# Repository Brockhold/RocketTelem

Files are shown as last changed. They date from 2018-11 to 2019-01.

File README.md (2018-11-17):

# CSS427-Project
# Team Rocket

### Members
**Robert Bachta**
**Ben Rockhold**

### Hardware / Sensors
- Adafruit Feather M0 Bluefruit
- Adafruit Feather M0 Adalogger
- (2) Sparkfun RFM69HCW 915MHz Wireless Transceiver
- Ultimate GPS Breakout v3
- Adafruit 10 DOF (LSM303DLHC Accel/Mag, L3GD20H Gyroscope, BMP180 Temp/Baro)

### Software
- Adafruit_GPS.h
- Adafruit_Sensor.h
- Adafruit_LSM303_U.h
- Adafruit_BMP085_U.h
- Adafruit_L3GD20_U.h
- Adafruit_10DOF.h
- RH_RF69.h

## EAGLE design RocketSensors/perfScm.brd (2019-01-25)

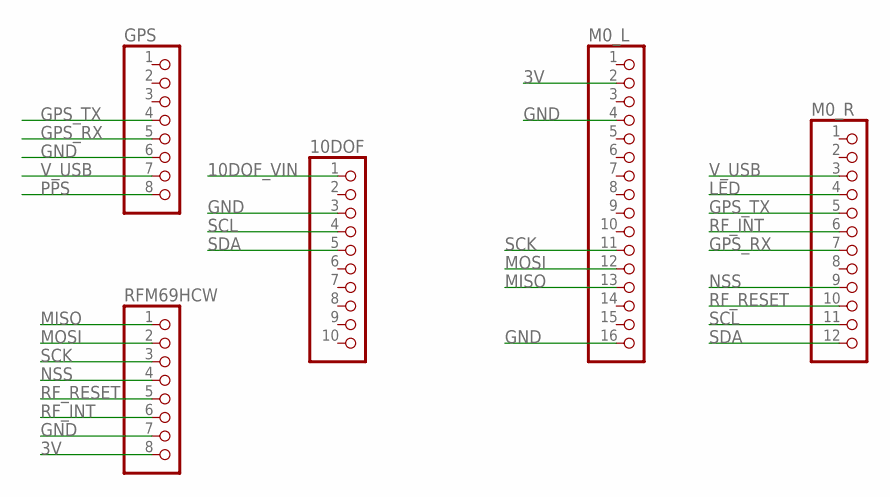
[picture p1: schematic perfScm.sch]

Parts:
10DOF: PINHD-1X10; 1X10
GPS: PINHD-1X8; 1X08
M0_L: PINHD-1X16; 1X16
M0_R: PINHD-1X12; 1X12
RFM69HCW: PINHD-1X8; 1X08

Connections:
3V: M0_L.2, RFM69HCW.8
10DOF_VIN: 10DOF.1
GND: 10DOF.3, GPS.6, M0_L.4, M0_L.16, RFM69HCW.7
GPS_RX: GPS.5, M0_R.7
GPS_TX: GPS.4, M0_R.5
LED: M0_R.4
MISO: M0_L.13, RFM69HCW.1
MOSI: M0_L.12, RFM69HCW.2
NSS: M0_R.9, RFM69HCW.4
PPS: GPS.8
RF_INT: M0_R.6, RFM69HCW.6
RF_RESET: M0_R.10, RFM69HCW.5
SCK: M0_L.11, RFM69HCW.3
SCL: 10DOF.4, M0_R.11
SDA: 10DOF.5, M0_R.12
V_USB: GPS.7, M0_R.3

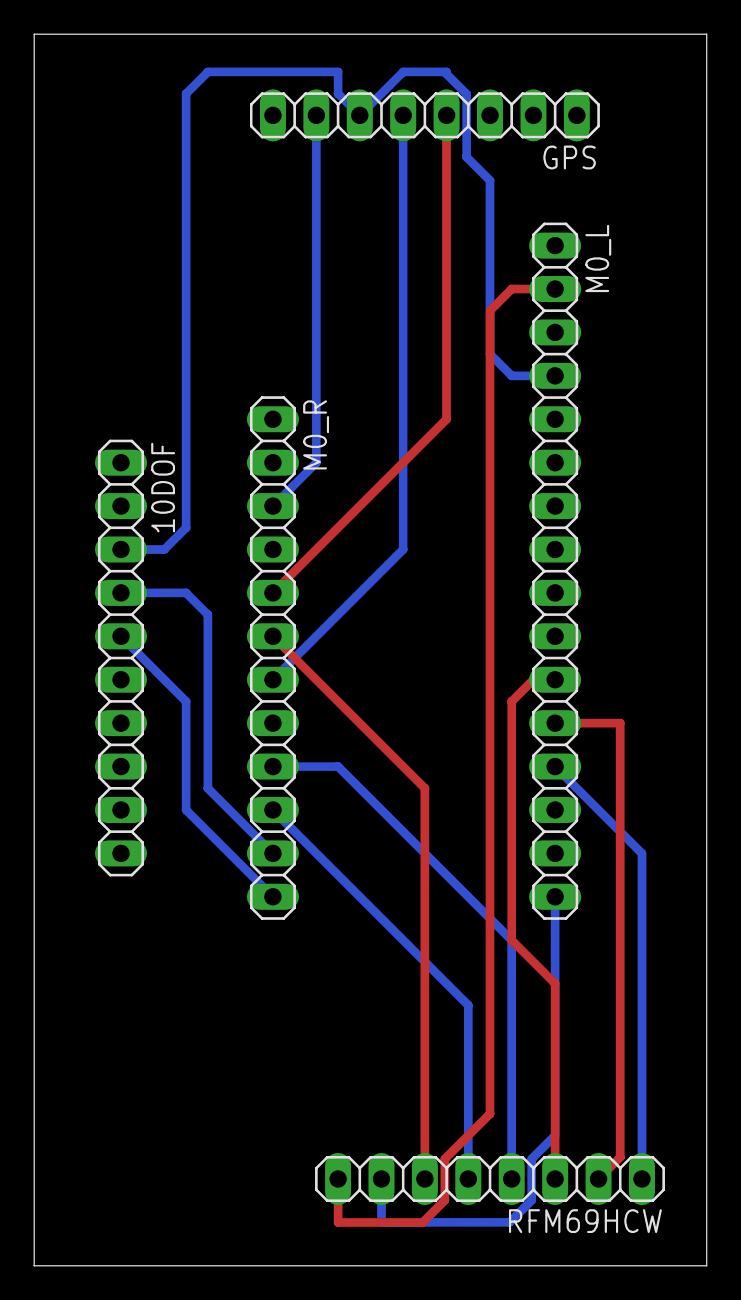
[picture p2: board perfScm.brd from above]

Board: 2 copper layers, 39.4 x 72.1 mm, 5 parts (0 on the bottom side), 13 nets.

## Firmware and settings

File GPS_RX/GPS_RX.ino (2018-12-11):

/*
 * Sketch for receiving sensor data from remote device..
 * 
 * Hardware: 
 *  Adafruit M0 (currently using BTLE Bluefruit, but not using the BT module)
 *  RF69HCW radio tranceiver connected to SPI (see config.h for pin details)
 */

#include "config.h"
#include "radioDecode.h"

RH_RF69 rf69(RFM69_CS, RFM69_INT); // radio driver instance
Adafruit_BluefruitLE_SPI ble(BLUEFRUIT_SPI_CS, BLUEFRUIT_SPI_IRQ, BLUEFRUIT_SPI_RST);

void usageMessage() {
  Serial.print(" | To set a polling rate enter a value between "); Serial.print(MINPERIOD);
  Serial.println("ms and 10000ms into the Serial input.");
  Serial.println(" |     Entering '0' or <emptystring> returns the current status and enters on-demand mode.");
  Serial.println(" |     Sending 's 0' and 's 1' enables or disables sd logging respectively.");
  Serial.println(" |     Sending 's 2' creates a new log file. Sending 's 9' erases the current log.");
}

// RF Initialize Method
void rfInitialize(){
  // manual reset
  digitalWrite(RFM69_RST, HIGH);
  delay(10);
  digitalWrite(RFM69_RST, LOW);
  delay(10);
  
  if (!rf69.init()) {
    Serial.println("[!] RFM69 radio init failed");
    while (1);
  }
  Serial.println("[!] RFM69 radio init OK!");
  
  // Defaults after init are 434.0MHz, modulation GFSK_Rb250Fd250, +13dbM (for low power module)
  // No encryption
  if (!rf69.setFrequency(RF69_FREQ)) {
    Serial.println("setFrequency failed");
  }

  // If you are using a high power RF69 eg RFM69HW, you *must* set a Tx power with the
  // ishighpowermodule flag set like this:
  rf69.setTxPower(20, true);  // range from 14-20 for power, 2nd arg must be true for 69HCW

  // The encryption key has to be the same as the one in the server
  uint8_t key[] = { 0x01, 0x02, 0x03, 0x04, 0x05, 0x06, 0x07, 0x08,
                    0x01, 0x02, 0x03, 0x04, 0x05, 0x06, 0x07, 0x08};
  rf69.setEncryptionKey(key);

  Serial.print("[!] RFM69 radio @");  Serial.print((int)RF69_FREQ);  Serial.println(" MHz");
}

bool btInit() {
  ble.begin(VERBOSE_MODE);
  ble.factoryReset();
  ble.echo(false);
  ble.verbose(false);
  
  ble.setMode(BLUEFRUIT_MODE_DATA);
}

// toggle the given pin by some count # of times for a duration of 'wait'
void blink(int pin, int count, int wait) {
  bool state = false;
  for (int i = 0; i < count * 2; i++) {
    digitalWrite(pin, state?HIGH:LOW);
    state = !state;
    delay(wait);
  }
}

/**
 * Reads integer from Serial to set polling rate on TX
 */
void readInput(){
  //send 0 or <emptystring> for on-demand mode. press enter to receive data.
  if(Serial.available()){

    //count of commands received
    ++terminalCounter;
    Serial.print("[!] Terminal command received. Current Count: ");
    Serial.println(terminalCounter);

    if(Serial.peek() == 's'){
      polling s;
      char sdCard = Serial.read(); //remove the s
      uint8_t sdCommand = Serial.parseInt(); //parse the number
      Serial.print("Sending SD Card update: "); Serial.print(sdCard); Serial.print(" "); Serial.println(sdCommand);
      s.sdCommand = sdCommand;
      s.message_id = counter;
      s.sdCard = sdCard;
      
      ++counter;
      rf69.send((uint8_t *)&s, sizeof(s));
      rf69.waitPacketSent();
      
      clearBuffer();
      usageMessage();
      return;
    }
    
    polling p;
    p.polling_rate = Serial.parseInt();
    p.message_id = counter;
    
    // clears out buffer for next read
    clearBuffer();

    // check validity of polling rate
    if ((p.polling_rate == 0) || (p.polling_rate >= MINPERIOD)) {
      // Send polling rate to TX
      ++counter;
      rf69.send((uint8_t *)&p, sizeof(p));
      rf69.waitPacketSent();
      
      // tell the user about the new polling rate, and optionally the usage
      if(p.polling_rate == 0){
        Serial.println("[!] Requested On-Demand update(s)");
        usageMessage();
      } else {
        Serial.print("[!] Polling rate has been updated to: ");
        Serial.print(p.polling_rate); Serial.println("ms");
      }
    } else {
      Serial.print(p.polling_rate); Serial.println("ms is too fast, please enter another value.");
      delay(2000);
    }
  }
}

void readBTInput() {
  //send 0 or <emptystring> for on-demand mode. press enter to receive data.
  if(ble.available()){

    //count of commands received
    ++terminalCounter;
    ble.print("[!] BT command received. Current Count: ");
    ble.println(terminalCounter);

    if(ble.peek() == 's'){
      polling s;
      char sdCard = ble.read(); //remove the s
      uint8_t sdCommand = ble.parseInt(); //parse the number
      ble.print("Sending SD Card update: "); ble.print(sdCard); ble.print(" "); ble.println(sdCommand);
      s.sdCommand = sdCommand;
      s.message_id = counter;
      s.sdCard = sdCard;
      
      ++counter;
      rf69.send((uint8_t *)&s, sizeof(s));
      rf69.waitPacketSent();
      
      clearBuffer();
      usageMessage();
      return;
    }
    
    polling p;
    p.polling_rate = ble.parseInt();
    p.message_id = counter;
    
    // clears out buffer for next read
    clearBuffer();

    // check validity of polling rate
    if ((p.polling_rate == 0) || (p.polling_rate >= MINPERIOD)) {
      // Send polling rate to TX
      ++counter;
      rf69.send((uint8_t *)&p, sizeof(p));
      rf69.waitPacketSent();
      
      // tell the user about the new polling rate, and optionally the usage
      if(p.polling_rate == 0){
        ble.println("[!] Requested On-Demand update(s)");
        usageMessage();
      } else {
        ble.print("[!] Polling rate has been updated to: ");
        ble.print(p.polling_rate); ble.println("ms");
      }
    } else {
      ble.print(p.polling_rate); ble.println("ms is too fast, please enter another value.");
      delay(2000);
    }
  }
}

/**
 * Sends received packet data to Serial
 */
void displayPacketData(statusStruct &packet){
  Serial.println("<packet>");
  Serial.println("  Metadata:");

  #if DEBUG
    Serial.print("    Raw = {"); 
    for (int i = 0; i < sizeof(packet); i++) {
      Serial.print(' '); Serial.print(((uint8_t *)&packet)[i]); 
    }
    Serial.println("}");
  #endif

  Serial.print("    Message ID: "); Serial.println(packet.message_id);
  Serial.print("    Current Polling Rate: ");
  if(packet.polling_rate < 2){
   Serial.println("On-Demand");
  }else{
   Serial.print(packet.polling_rate); Serial.println("ms");
  }
  Serial.print("    Logging Status: "); Serial.println(packet.sdStatus ? "Enabled" : "Disabled");
  
  Serial.print("  Date & Time:    "); 
  // Year/Month/Day
  Serial.print(packet.year); Serial.print("/");
  Serial.print(packet.month); Serial.print("/");
  Serial.print(packet.day);
  Serial.print("    ");
  // Hour:Minute:Second
  Serial.print(packet.hour); Serial.print(":");
  Serial.print(packet.minute); Serial.print(":");
  Serial.println(packet.seconds);

  Serial.println("  Transmitter Status:");
  
  // Transmitter battery level
  Serial.print("    Battery voltage: "); Serial.print((float)packet.batt_level / 1024); Serial.println("v");
  Serial.print("    Temperature (C): "); Serial.println(packet.temperature);

  Serial.println("  Physical Status:");
  
  // GPS reception status
  Serial.print("    GPS fix: "); Serial.print(packet.fix?"Yes":"No");
  Serial.print(", Quality: "); Serial.print(packet.fixquality);
  Serial.print(", Satellites: "); Serial.println(packet.satellites);

    // If there is a GPS fix, print the reported Lat & Ln
    if (packet.fix) {
      Serial.print("    Location: ");
      if ((char) packet.lat == 'S') Serial.print("-");
      Serial.print(packet.latitude_fixed/10000000); Serial.print("."); Serial.print(packet.latitude_fixed % 10000000);
      Serial.print(", ");
      if ((char) packet.lon == 'W') Serial.print("-");
      Serial.print(packet.longitude_fixed/10000000); Serial.print("."); Serial.println(packet.longitude_fixed % 10000000);
    } else {
      Serial.println("    Location: +000.000000, +000.000000");
    }
    // Barometric altimeter status
    Serial.print("    Altitude: "); Serial.println(abs(packet.bar_alt));
    // Accelerometer status
    Serial.print("    Accelerometer {"); 
    Serial.print(" Pitch: "); Serial.print((float)(packet.pitch) / 700); 
    Serial.print(" Roll: "); Serial.print((float)(packet.roll) / 300);
    Serial.print(" Heading: "); Serial.print((float)(packet.heading) / 180);
    Serial.println(" }");
    //Serial.print("Compass Heading: "); Serial.println(packet.mag_heading);
    
    Serial.println("</packet>"); Serial.println();
 }

void btPrint(statusStruct &packet) {
  ble.print("Packet ID: "); ble.print(packet.message_id);
  ble.print(" rate: ");
  if(packet.polling_rate < 2){
   ble.println("On-Demand");
  }else{
   ble.print(packet.polling_rate); ble.println("ms");
  }
  ble.print("Log: "); ble.println(packet.sdStatus ? "Yes" : "No");
  
  // Year/Month/Day
  ble.print(packet.year); ble.print("/");
  ble.print(packet.month); ble.print("/");
  ble.print(packet.day);
  ble.print("    ");
  // Hour:Minute:Second
  ble.print(packet.hour); ble.print(":");
  ble.print(packet.minute); ble.print(":");
  ble.println(packet.seconds);

  // Transmitter battery level
  ble.print((float)packet.batt_level / 1024); ble.println("v");
  ble.print(packet.temperature); ble.println("c"); 

  // GPS reception status
  ble.print("Fix: "); ble.print(packet.fix?"Yes":"No");
  ble.print(", Q: "); ble.print(packet.fixquality);
  ble.print(", Sats: "); ble.println(packet.satellites);

    // If there is a GPS fix, print the reported Lat & Ln
    if (packet.fix) {
      ble.print("Loc: ");
      if ((char) packet.lat == 'S') ble.print("-");
      ble.print(packet.latitude_fixed/10000000); ble.print("."); ble.print(packet.latitude_fixed % 10000000);
      ble.print(", ");
      if ((char) packet.lon == 'W') ble.print("-");
      ble.print(packet.longitude_fixed/10000000); ble.print("."); ble.println(packet.longitude_fixed % 10000000);
    }
    // Barometric altimeter status
    ble.print("Alt: "); Serial.println(packet.bar_alt);
    // Accelerometer status
    ble.print("Accel{"); 
    ble.print(" P: "); ble.print((float)(packet.pitch) / 700); 
    ble.print(" R: "); ble.print((float)(packet.roll) / 300);
    ble.print(" H: "); ble.print((float)(packet.heading) / 180);
    ble.println(" }\n");
}

 /*
 * SETUP
 */
void setup() {
  Serial.begin(115200);
  while (!Serial) { delay(1); } // wait until serial console is open, remove if not tethered to computer

  pinMode(LED_BUILTIN, OUTPUT); digitalWrite(LED_BUILTIN, LOW);
  pinMode(RFM69_RST, OUTPUT);
  digitalWrite(RFM69_RST, LOW);

  rfInitialize();
  btInit();
  usageMessage();
}

/*
 * Program Loop
 */

void loop() {
  
  readInput(); // check for new polling rate directive from user
  //readBTInput();
  struct statusStruct radioPacket;
  uint8_t len = sizeof(radioPacket);
  if (rf69.available() && rf69.recv((uint8_t *)&radioPacket, &len)) {
    if (!len) return;

    // blink LED to show activity
    blink(LED_BUILTIN, 1, 50);

    Serial.print("Received ["); 
    Serial.print(len); 
    Serial.print("] @RSSI ");
    Serial.println(rf69.lastRssi(), DEC);

    displayPacketData(radioPacket);
    btPrint(radioPacket);
  }
}

void clearBuffer(){
  while(Serial.available() > 0){
      Serial.read();
    }
}

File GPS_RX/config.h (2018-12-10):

// User interaction options
// Set this to true for additional sensor details
#define DEBUG false
// In headless mode, nothing is written to Serial0 (USB serial)
#define HEADLESS false
// In wait is enabled, the system will pause until Serial0 connects.
#define WAIT true

/************ Radio Setup ***************/
#define RF69_FREQ 915.0     // Label on breakout
#define RFM69_CS      6     // NSS
#define RFM69_INT     11    // DIO 0
#define RFM69_RST     12    // RST
#define PACKET_LEN    24    // Expected packet size

#include <SPI.h>
#include <RH_RF69.h>

#include "Adafruit_BLE.h"
#include "Adafruit_BluefruitLE_SPI.h"
#include "Adafruit_BluefruitLE_UART.h"

unsigned int counter = 0;
unsigned int terminalCounter = 0;

#define MINPERIOD 100


// COMMON SETTINGS
// ----------------------------------------------------------------------------------------------
// These settings are used in both SW UART, HW UART and SPI mode
// ----------------------------------------------------------------------------------------------
#define BUFSIZE                        128   // Size of the read buffer for incoming data
#define VERBOSE_MODE                   true  // If set to 'true' enables debug output


// SOFTWARE UART SETTINGS
// ----------------------------------------------------------------------------------------------
// The following macros declare the pins that will be used for 'SW' serial.
// You should use this option if you are connecting the UART Friend to an UNO
// ----------------------------------------------------------------------------------------------
#define BLUEFRUIT_SWUART_RXD_PIN       9    // Required for software serial!
#define BLUEFRUIT_SWUART_TXD_PIN       10   // Required for software serial!
#define BLUEFRUIT_UART_CTS_PIN         11   // Required for software serial!
#define BLUEFRUIT_UART_RTS_PIN         -1   // Optional, set to -1 if unused


// HARDWARE UART SETTINGS
// ----------------------------------------------------------------------------------------------
// The following macros declare the HW serial port you are using. Uncomment
// this line if you are connecting the BLE to Leonardo/Micro or Flora
// ----------------------------------------------------------------------------------------------
#ifdef Serial1    // this makes it not complain on compilation if there's no Serial1
  #define BLUEFRUIT_HWSERIAL_NAME      Serial1
#endif


// SHARED UART SETTINGS
// ----------------------------------------------------------------------------------------------
// The following sets the optional Mode pin, its recommended but not required
// ----------------------------------------------------------------------------------------------
#define BLUEFRUIT_UART_MODE_PIN        12    // Set to -1 if unused


// SHARED SPI SETTINGS
// ----------------------------------------------------------------------------------------------
// The following macros declare the pins to use for HW and SW SPI communication.
// SCK, MISO and MOSI should be connected to the HW SPI pins on the Uno when
// using HW SPI.  This should be used with nRF51822 based Bluefruit LE modules
// that use SPI (Bluefruit LE SPI Friend).
// ----------------------------------------------------------------------------------------------
#define BLUEFRUIT_SPI_CS               8
#define BLUEFRUIT_SPI_IRQ              7
#define BLUEFRUIT_SPI_RST              4    // Optional but recommended, set to -1 if unused

// SOFTWARE SPI SETTINGS
// ----------------------------------------------------------------------------------------------
// The following macros declare the pins to use for SW SPI communication.
// This should be used with nRF51822 based Bluefruit LE modules that use SPI
// (Bluefruit LE SPI Friend).
// ----------------------------------------------------------------------------------------------
#define BLUEFRUIT_SPI_SCK              13
#define BLUEFRUIT_SPI_MISO             12
#define BLUEFRUIT_SPI_MOSI             11

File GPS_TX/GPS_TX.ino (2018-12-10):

/*
 * Sketch for transmitting sensor data via radio.
 * Designed to run on an Adafruit M0.
 * See config.h for a list of pins connected to hardware and
 * a list of all necessary Arduino libraries.
 */

// Configuration files, helper methods, global variables
#include "config.h"

/*
 * Init conneted devices on SPI and serial
 */
void setup() {
  // Set IO pin modes
  pinMode(LED_BUILTIN, OUTPUT);     
  pinMode(RFM69_RST, OUTPUT);
  // Assign pins to SERCOM functionality
  pinPeripheral(PIN_SERIAL2_TX, PIO_SERCOM);
  pinPeripheral(PIN_SERIAL2_RX, PIO_SERCOM);

  if (!HEADLESS) {
    if (WAIT) while (!Serial);  // hold the system hostage until it's time to start
    Serial.begin(115200); // talk to the host at a brisk rate, so we have time to write without dropping chars
    Serial.println("Let's Start!");
    Serial.print("Packet size: "); Serial.print(sizeof(statusStruct)); Serial.println(" bytes");
  }
  rfInitialize();
  gpsInitialize();
  initSensors();
  if (sdInitialize(SD_CS)) {
    logFile = SD.open(fileName, FILE_WRITE);
    if (logFile) {
      logFile.println("Log start");
      logFile.flush();
    }
  }
}

/*
 * Read sensor data periodically or on-demand, compose a packet, and send to remote receiver
 */
void loop() {
  // look for user input about new polling rate
  onDemand = checkPollingUpdate();

  //checkSdCardUpdate();
  
  // pull chars one at a time from the GPS
  GPS.read();
  
  // if a sentence is received, we can check the checksum, parse it...
  if (GPS.newNMEAreceived()) {
    if (!GPS.parse(GPS.lastNMEA())) // this also sets the newNMEAreceived() flag to false
      return; // we can fail to parse; wait for another message
  }
  
  // wait around for the sensor update time
  if (onDemand || (updateFrequency >= 100 && millis() - timer >= updateFrequency)) {
    onDemand = false; // if in onDemand mode, return to waiting
    // Build the radio packet to be sent
    statusStruct radioPacket = getSensorData();
    
    // Send data to RF
    rf69.send((uint8_t*)&radioPacket, sizeof(radioPacket));
    rf69.waitPacketSent();

    // blink LED to show activity
    blink(LED_BUILTIN, 1, 50);

    #if !HEADLESS

    Serial.print("Packet {"); 
    for (int i = 0; i < sizeof(radioPacket); i++) {
      Serial.print(((uint8_t *)&radioPacket)[i]); Serial.print(' ');
    }
    Serial.println("}"); 
      
    #endif
    
    outputToSerial(&radioPacket);

    logToSdCard(&radioPacket);
    
    timer = millis(); // reset the timer
  }
}

/*
 * Gets all the sensor data and returns the struct
 * If any even continues to fail the whole program fails
 */
statusStruct getSensorData(){
  // Event structures for each sensor
    sensors_event_t accel_event;
    sensors_event_t mag_event;
    sensors_event_t bmp_event;
    sensors_vec_t   orientation; // vector of floats for pitch/roll/heading

    uint8_t retry = 3;
    // these may fail...if either of them do retry
    // get sensor events
    getSensorEvents(&accel_event, &mag_event, &bmp_event);

    // fill out the orientation vector struct (floats) with accel data
    dof.accelGetOrientation(&accel_event, &orientation);

    // add magnetic heading to orientation struct
    dof.magGetOrientation(SENSOR_AXIS_Z, &mag_event, &orientation);
    
    // get temperature as a float and then force into integer representaton
    float temp_float;
    bmp.getTemperature(&temp_float);
    int16_t temp_int = temp_float;

    // get barometric pressure and convert to altitude
    int16_t altitude_int = bmp.pressureToAltitude(SENSORS_PRESSURE_SEALEVELHPA, bmp_event.pressure, temp_float);

    ++counter; // Increase message counter for tracking packets

    // take all those structures and copy their values into the radio packet struct
    return buildPacket(orientation, altitude_int, temp_int, &GPS, updateFrequency, sdEnabled);
}

/*
 * Checks to see if a polling packet was received.
 * updates the polling frequency based on the received value. 
 * Values is in milliseconds and contrained between 100 and 10000.
 * Returns true iff the user has requested an on-demand update.
 */
bool checkPollingUpdate(){
  polling p;
  uint8_t len = sizeof(p);

  // check to see if the receiver sent a new poll rate
  if(rf69.available() && rf69.recv((uint8_t *)&p, &len)){
    
    #if !HEADLESS
    Serial.print("Received [");
    Serial.print(len);
    Serial.print("] Message ID: ");
    Serial.print(p.message_id);
    Serial.print(" Value: ");
    Serial.println(p.polling_rate);
    #endif

    // Placing this here to resolve a packet receive bug
    // I dont like this but it works.
    if(p.sdCard == 's'){
      switch(p.sdCommand){
        case 0: //disable logging
          sdEnabled = false;
          break;
        case 1: //enable logging
          sdEnabled = true;
          break;
        case 2: //start a new log
          logFile.flush();
          logFile.close();
          sdClock = millis();
          fileName = String("logFile") + String(sdClock) + String(".txt");
          logFile = SD.open(fileName, FILE_WRITE);
          if (logFile) {
            logFile.println("Log start");
            logFile.flush();
          }
          break;
        case 9: //erase the current log
          logFile.close();
          SD.remove(fileName);
          logFile = SD.open(fileName, FILE_WRITE);
          if (logFile) {
            logFile.println("Log start");
            logFile.flush();
          }
          break;
        default:
          break;
      }

      return onDemand;
    }
    

    if(p.polling_rate == 0){
      updateFrequency = p.polling_rate;
      return true;
    } else {
      // Constrain the value and update the frequency
      updateFrequency = constrain(p.polling_rate, 100, 10000);
    }
  }
  return false;
}

void logToSdCard(StatusStruct* message){
  if(sdEnabled){
    String data = structToString(message);

    if(logFile){
      logFile.println(data);
      logFile.flush();
      #if !HEADLESS
      Serial.print("Data logged: ");
      Serial.println(data);
      #endif
    }
  }
  return;
}
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

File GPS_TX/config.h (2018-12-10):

// User interaction options

#define HEADLESS false // In headless mode, nothing is written to Serial0 (USB serial)
#define WAIT false // In wait is enabled, the system will halt until Serial0 connects.
uint16_t updateFrequency = 1000; // Dynamic polling rate
unsigned long counter = 0; // Message Counter

#define VBATPIN A7 // pin used to measure battery voltage via a 1/2 divider.

// Serial port pinmux for GPS comms, allows for multiple hardware-accelerated serial ports via SERCOM
#define PIN_SERIAL2_RX       (34ul)               // Pin description number for PIO_SERCOM on D12
#define PIN_SERIAL2_TX       (36ul)               // Pin description number for PIO_SERCOM on D10
#define PAD_SERIAL2_TX       (UART_TX_PAD_2)      // SERCOM pad 2
#define PAD_SERIAL2_RX       (SERCOM_RX_PAD_3)    // SERCOM pad 3
#define GPSECHO false // echo the GPS data to the Serial console?

// RFM69HCW Radio config
#define RF69_FREQ     915.0                       // radio frequency (MUST MATCH HARDWARE!)
#define RFM69_CS      6                           // chip select on pin D6
#define RFM69_INT     11                          // data ready interrupt on pin D11
#define RFM69_RST     5                           // radio soft-reset on pin D24

// SD card configuration
#define SD_CS 4                                   // chip select on pin D4

// Built in Arduino libraries
#include <SPI.h>
#include <SD.h>
#include <Wire.h>
#include "wiring_private.h" // access to private pinPeripheral() function

// External libraries (all available via library manager as of 10/18)
#include <Adafruit_GPS.h>
#include <Adafruit_Sensor.h>
#include <Adafruit_LSM303_U.h>
#include <Adafruit_BMP085_U.h>
#include <Adafruit_L3GD20_U.h>
#include <Adafruit_10DOF.h>
#include <RH_RF69.h>

#include "radioEncode.h" // custom radio packet structure

// Radio object
RH_RF69 rf69(RFM69_CS, RFM69_INT); // radio driver instance

// Sensor objects
Adafruit_10DOF                dof   = Adafruit_10DOF();
Adafruit_LSM303_Accel_Unified accel = Adafruit_LSM303_Accel_Unified(30301);
Adafruit_LSM303_Mag_Unified   mag   = Adafruit_LSM303_Mag_Unified(30302);
Adafruit_BMP085_Unified       bmp   = Adafruit_BMP085_Unified(18001);

// define the GPS's hardware serial port
Uart Serial2(&sercom1, PIN_SERIAL2_RX, PIN_SERIAL2_TX, PAD_SERIAL2_RX, PAD_SERIAL2_TX);
// Interrupt handler for Serial2
void SERCOM1_Handler() { Serial2.IrqHandler(); }
#define GPSSerial Serial2
Adafruit_GPS GPS(&GPSSerial); // Init the GPS handler object with the assigned serial port

// Data logging SD card configuration
File logFile;
bool card_available = false;

// Give the barometic sensor object the appropriate SLP for altitude measurements
float seaLevelPressure = SENSORS_PRESSURE_SEALEVELHPA;

// This timer is used in the loop() method to service the sensor checking
unsigned long timer = millis();

// SD Card config data
unsigned long sdClock = millis(); // keeps the filename somewhat unique. good enough
String fileName = String("logFile") + String(sdClock) + String(".txt"); // filename to concat sdClock to
boolean sdEnabled = true;

// set onDemand to true when the user requests an update, and returned to false after update has been serviced
bool onDemand = false; 

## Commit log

2018-10-02 Initial commit for GPS_TX
    First prototype for sensor reading and radio transmission. Successfully implements UART mapping for connecting the GPS to a dedicated hardware serial port, and communicates with the RFM69HCW radio vi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
2018-10-02 Initial commit of GPS_RX
    Simple sketch to read all messages from the RFM69HCW radio over SPI and dump them to serial for the host to look at. Performs some janky message parsing, which does not appear to work.
2018-10-03 Minor printout formatting changes
2018-10-09 Updated fixed decimal conversion
    Minor corrections to printout and packet decode. GPS position is now printed accurately, and in standard format.
    [GPS_RX.ino, GPS_TX.ino]
2018-10-10 Rearranged TX program
    Moved all #define into a seperate config file, updated comments, corrected location of some config methods and their order.
    Also added SD card initialization, not currently used anywhere.
    [GPS_TX.ino, config.h]
2018-10-18 Swapped out shitty math for casting a struct to the data type of the packet
    [GPS_TX.ino, config.h]
2018-11-08 Initial re-arranging TX code for 10-dof sensor
2018-11-16 updated TX and RX struct to reflect 10dof sensors
2018-11-16 removed RX prints for sensors that do not exist
2018-11-16 Added prints for added structure values.
2018-11-16 jammed sensors into TX message, added same to debug printout
    [GPS_TX.ino]
2018-11-17 Beginning stages of polling system. Additional work required. WIP
2018-11-21 added battery voltage byte to encode/decode headers
2018-11-25 Added #define for minimum valid polling time
    Not currently matched on TX side, where it is hard-coded.
2018-11-25 Partly reverted some logic mistakes, updated usage message
    [GPS_RX.ino, config.h]
2018-11-26 Added battery voltage measurement and reporting
    +1 sensor, yay
2018-11-26 Minor comment changes for RX printout readability
    logic unchanged, but printout much more readable (and has dumb HTML-like headers too...)
2018-11-30 added type cast and scaling to the pitch/roll/heading values prior to transmission
2018-11-30 fixed a single-character bug preventing 10Hz updates...
    [GPS_TX.ino]
2018-12-02 swap pitch and roll to unsigned ints
    [config.h]
2018-12-02 Revert "swap pitch and roll to unsigned ints"
    This reverts commit 8f3b353b672997278dfbee4f86e86ccf2ba49c5d.
    [config.h]
2018-12-02 use signed ints for pitch and roll so they can go negative
    second commit...
2018-12-09 Added SD card packet TX & RX. functionality doesnt exist, just the commands are currently sending
2018-12-11 reduced btle prints slightly
2019-01-25 Added circuit schematic because well why not
    [perfScm.brd, perfScm.sch]
